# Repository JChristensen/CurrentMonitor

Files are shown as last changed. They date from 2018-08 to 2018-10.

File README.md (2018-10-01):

# Current Monitor
https://github.com/JChristensen/CurrentMonitor  
README file  
Jack Christensen  
Aug-2018

## License
  
Current Monitor by Jack Christensen is licensed under a [Creative Commons Attribution-ShareAlike 4.0 International License](http://creativecommons.org/licenses/by-sa/4.0/).

## Overview
The Current Monitor is an Arduino Uno-compatible board designed to function as a sensor node in an XBee network. While the board was primarily designed to interface to current transformers, it is also general enough to have wider applicability. Features include:
- ATmega328P microcontroller
- interface circuitry for two current transformers
- two analog pins (for current transformers) and four digital pins brought out to screw-type terminal blocks
- three on-board LEDs
- interface circuitry and 3.3V supply for the XBee module
- powered from most any 7-12VDC wall wart with a 2.5mm plug

[Hardware design](https://github.com/JChristensen/CurrentMonitor) and [an Arduino Current Transformer library](https://github.com/JChristensen/CurrentTransformer) are available on GitHub.  
PC boards can be ordered from [OSH Park](https://www.oshpark.com/shared_projects/QCjudQBh).  
A bill of materials is available at [Mouser Electronics](https://www.mouser.com/ProjectManager/ProjectDetail.aspx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) and also in the [GitHub repo](https://github.com/JChristensen/CurrentMonitor).  

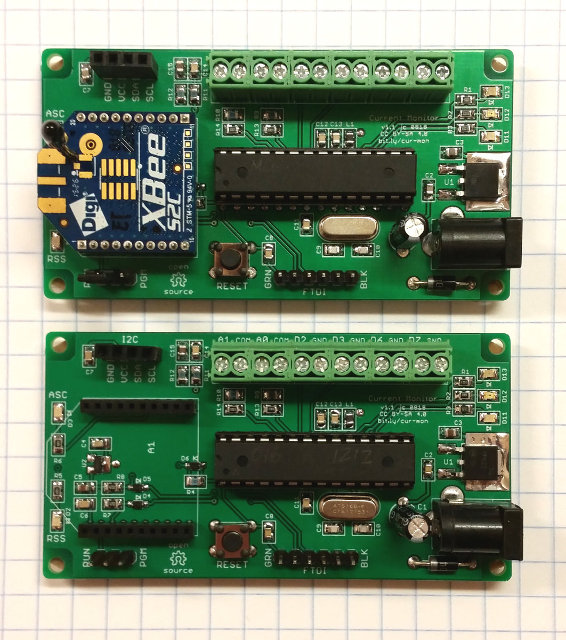
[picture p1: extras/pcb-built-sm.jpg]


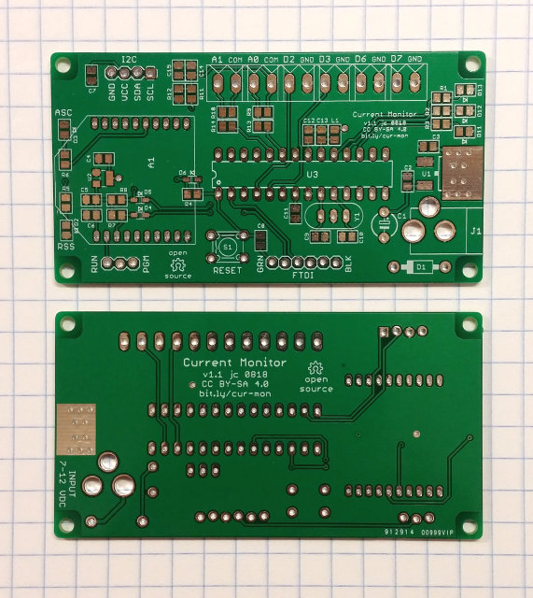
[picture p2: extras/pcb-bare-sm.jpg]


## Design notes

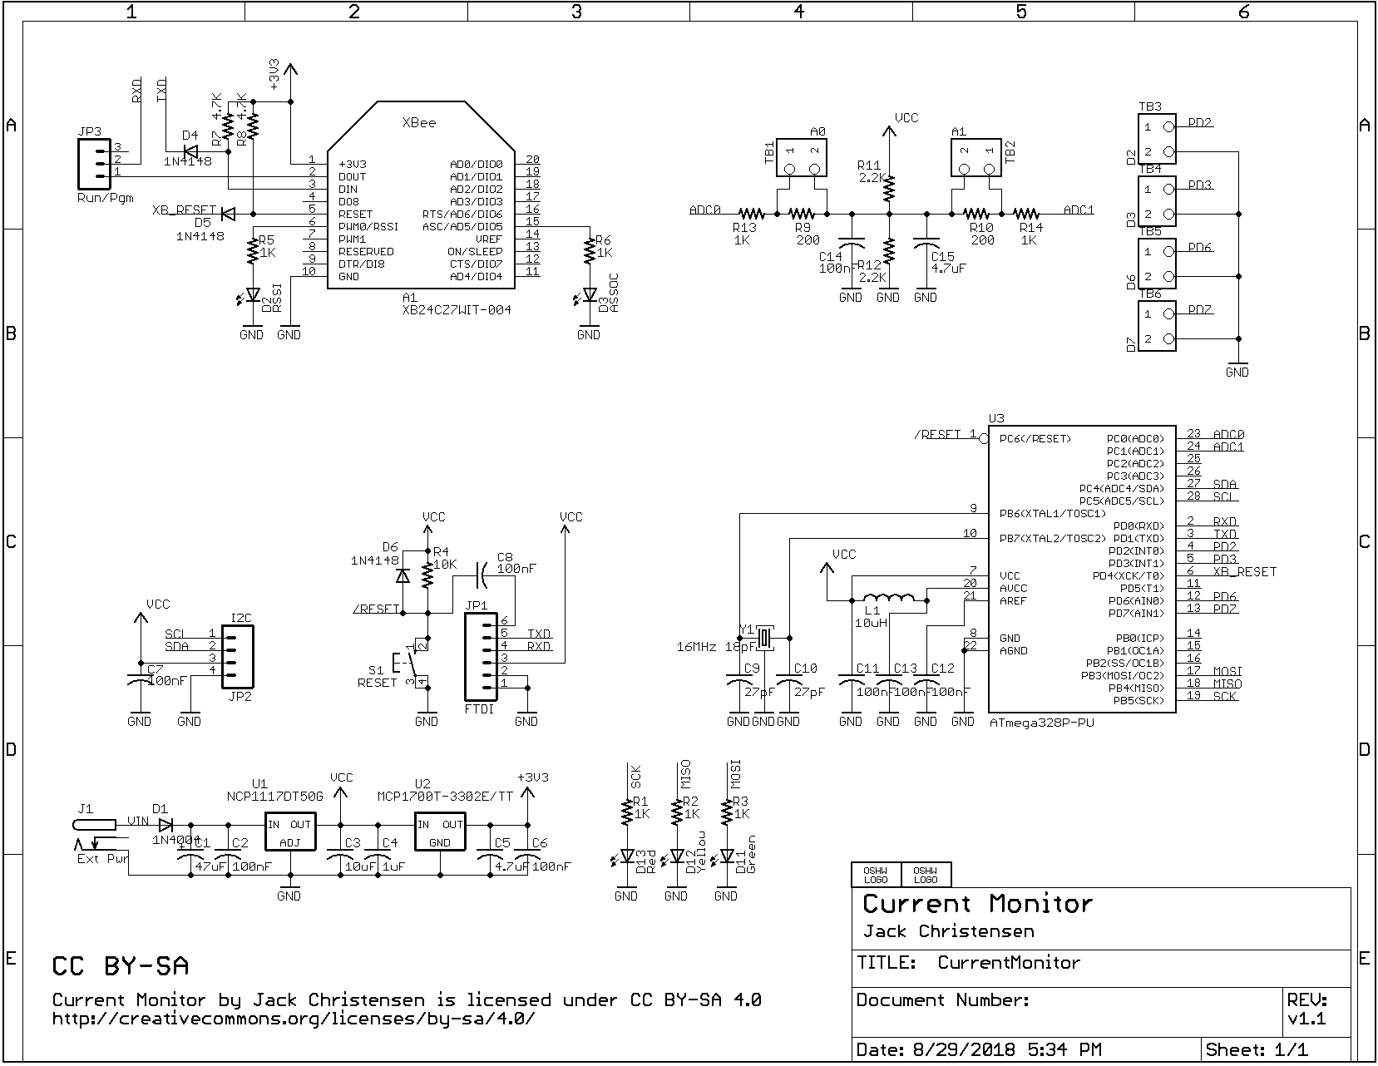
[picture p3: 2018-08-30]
schematic.png

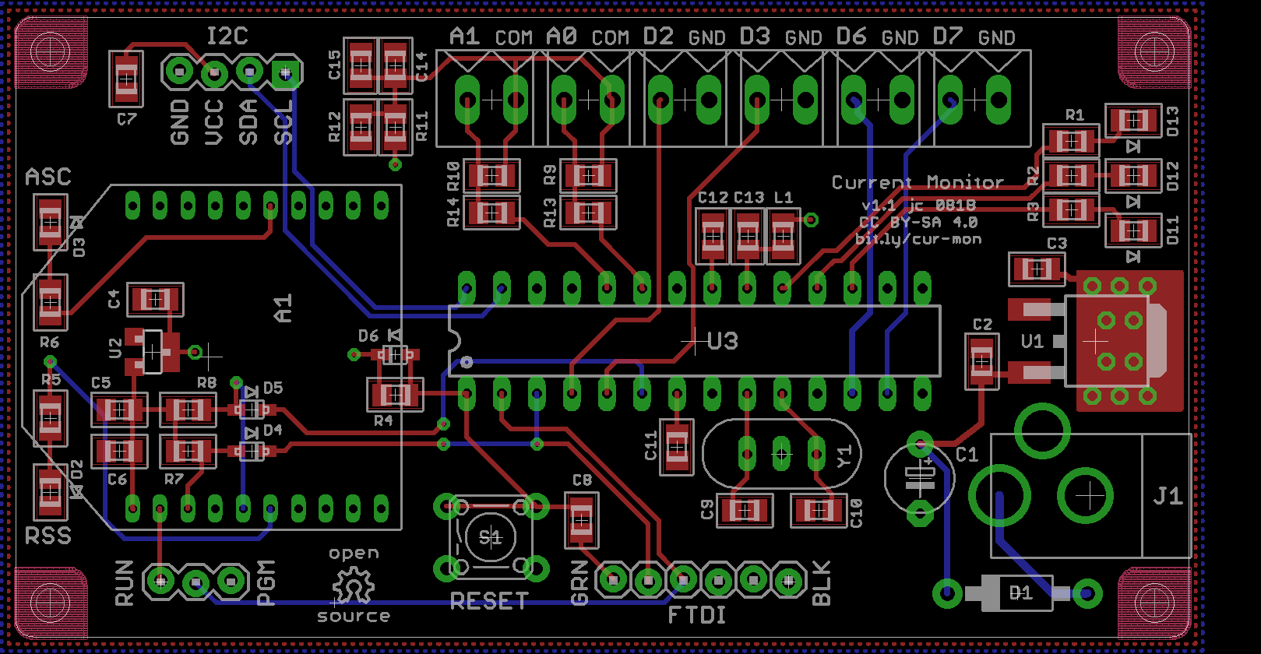
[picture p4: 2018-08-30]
board.png

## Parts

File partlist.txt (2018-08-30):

Partlist

Exported from CurrentMonitor.sch at 8/30/2018 4:15 PM

EAGLE Version 7.5.0 Copyright (c) 1988-2015 CadSoft

Assembly variant: 

Part     Value             Device             Package        Library  Sheet

A1       XB24CZ7WIT-004    ULINK_XBEEOVALPADS XBEE_OVAL_PADS _jc      1
C1       47uF              CPOL-USE5-5        E5-5           _jc      1
C2       100nF             C-USM0805          M0805          _jc      1
C3       10uF              C-USM0805          M0805          _jc      1
C4       1uF               C-USM0805          M0805          _jc      1
C5       4.7uF             C-USM0805          M0805          _jc      1
C6       100nF             C-USM0805          M0805          _jc      1
C7       100nF             C-USM0805          M0805          _jc      1
C8       100nF             C-USM0805          M0805          _jc      1
C9       27pF              C-USM0805          M0805          _jc      1
C10      27pF              C-USM0805          M0805          _jc      1
C11      100nF             C-USM0805          M0805          _jc      1
C12      100nF             C-USM0805          M0805          _jc      1
C13      100nF             C-USM0805          M0805          _jc      1
C14      100nF             C-USM0805          M0805          _jc      1
C15      4.7uF             C-USM0805          M0805          _jc      1
D1       1N4004            DIODE1N400X        1N400X         _jc      1
D2       RSSI              LEDD0805A          D0805A         _jc      1
D3       ASSOC             LEDD0805           D0805          _jc      1
D4       1N4148            DIODESOD-323F-A    SOD-323F-A     _jc      1
D5       1N4148            DIODESOD-323F-A    SOD-323F-A     _jc      1
D6       1N4148            DIODESOD-323F      SOD-323F       _jc      1
D11      Green             LEDD0805           D0805          _jc      1
D12      Yellow            LEDD0805           D0805          _jc      1
D13      Red               LEDD0805           D0805          _jc      1
J1       Ext Pwr           POWER-JACK         KLDX-0202      _jc      1
JP1      FTDI              M06LOCK            1X06_LOCK      SparkFun 1
JP2      I2C               M04LOCK            1X04_LOCK      SparkFun 1
JP3      Run/Pgm           M03LOCK            1X03_LOCK      SparkFun 1
L1       10uH              INDUCTORM0805      M0805          _jc      1
R1       1K                R-US_M0805         M0805          _jc      1
R2       1K                R-US_M0805         M0805          _jc      1
R3       1K                R-US_M0805         M0805          _jc      1
R4       10K               R-US_M0805         M0805          _jc      1
R5       1K                R-US_M0805         M0805          _jc      1
R6       1K                R-US_M0805         M0805          _jc      1
R7       4.7K              R-US_M0805         M0805          _jc      1
R8       4.7K              R-US_M0805         M0805          _jc      1
R9       200               R-US_M0805         M0805          _jc      1
R10      200               R-US_M0805         M0805          _jc      1
R11      2.2K              R-US_M0805         M0805          _jc      1
R12      2.2K              R-US_M0805         M0805          _jc      1
R13      1K                R-US_M0805         M0805          _jc      1
R14      1K                R-US_M0805         M0805          _jc      1
S1       RESET             10-XXOCT           B3F-10XXOCT    _jc      1
TB1      A0                OST-TB-23.5MM      OST-TB-2-3.5MM _jc      1
TB2      A1                OST-TB-23.5MM      OST-TB-2-3.5MM _jc      1
TB3      D2                OST-TB-23.5MM      OST-TB-2-3.5MM _jc      1
TB4      D3                OST-TB-23.5MM      OST-TB-2-3.5MM _jc      1
TB5      D6                OST-TB-23.5MM      OST-TB-2-3.5MM _jc      1
TB6      D7                OST-TB-23.5MM      OST-TB-2-3.5MM _jc      1
U1       NCP1117DT50G      LD117ADT50TR       DPACK          v-reg    1
U2       MCP1700T-3302E/TT MCP1700SOT23-W     SOT23-W        _jc      1
U3       ATmega328P-PU     AVR-MEGA8-PPTH     DIL28-3        SparkFun 1
Y1       16MHz 18pF        RESONATOR          RESONATOR      _jc      1

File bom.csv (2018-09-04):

Current Monitor
Bill of materials
https://www.mouser.com/ProjectManager/ProjectDetail.aspx?AccessID=cceb9dd570
Part No. | Order Qty. | Mouser # | Mfr. # | Manufacturer | Description
A1 | 2 | 855-M22-7131042 | M22-7131042 | Harwin | Headers & Wire Housings 10 PIN SIL VERTICAL GOLD+TIN SOCKET
A1 | 1 | 888-XB24CZ7WIT-004 | XB24CZ7WIT-004 | Digi International | Zigbee Modules (802.15.4) XBee ZB S2C TH Wire Antenna
C1 | 1 | 667-ECA-1CM470B | ECA-1CM470B | Panasonic | Aluminum Electrolytic Capacitors - Radial Leaded Al Lytic Cap 85C Radial M Series
C2, C6, C7, C8, C11-14 | 8 | 581-08053C104K | 08053C104KAT2A | AVX | Multilayer Ceramic Capacitors MLCC - SMD/SMT 25V .1uF X7R 0805 10%
C3 | 1 | 963-LMK212BJ106KG-T | LMK212BJ106KG-T | Taiyo Yuden | Multilayer Ceramic Capacitors MLCC - SMD/SMT 10uF 10V X5R +/-10% 0805 Gen Purp
C4 | 1 | 81-GRM21BR61C105KA1K | GRM21BR61C105KA01K | Murata | Multilayer Ceramic Capacitors MLCC - SMD/SMT 1uf 16V X5R +/-10% 0805
C5, C15 | 2 | 963-LMK212B7475KG-T | LMK212B7475KG-T | Taiyo Yuden | Multilayer Ceramic Capacitors MLCC - SMD/SMT 4.7uF 10V X7R +/-10% 0805 Gen Purp
C9, C10 | 2 | 603-CC805JRNPO9BN270 | CC0805JRNPO9BN270 | Yageo | Multilayer Ceramic Capacitors MLCC - SMD/SMT 27pF 50V NPO 5%
D1 | 1 | 863-1N4004G | 1N4004G | ON Semiconductor | Rectifiers 400V 1A Standard
D12 | 1 | 859-LTST-C171KSKT | LTST-C171KSKT | Lite-On | Standard LEDs - SMD Yellow Clear 587nm
D2, D13 | 2 | 859-LTST-C171KRKT | LTST-C171KRKT | Lite-On | Standard LEDs - SMD Red Clear 55MCD
D3, D11 | 2 | 859-LTST-C171KGKT | LTST-C171KGKT | Lite-On | Standard LEDs - SMD Green Clear 571nm
D4, D5, D6 | 3 | 512-1N4148WS | 1N4148WS | ON Semiconductor | Diodes - General Purpose, Power, Switching Small Signal Diode
J1 | 1 | 806-KLDX-0202-B | KLDX-0202-B | Kycon | DC Power Connectors 2.5mm PCB JACK POWER JACK
JP1 | 1 |  |  |  | 0.1” Header, male, 6-position
JP2 | 1 |  |  |  | 0.1” Header, female, 4-position
JP3 | 1 |  |  |  | 0.1” Header, male, 3-position
JP3 | 1 |  |  |  | Shorting block for 0.1” header
L1 | 1 | 963-LBR2012T100K | LBR2012T100K | Taiyo Yuden | Fixed Inductors 0805 10uH 468mOhms +/-10%Tol 150mA
R1-3, R5-6, R13-14 | 7 | 603-RC0805FR-071KL | RC0805FR-071KL | Yageo | Thick Film Resistors - SMD 1K OHM 1%
R11, R12 | 2 | 603-RC0805FR-072K2L | RC0805FR-072K2L | Yageo | Thick Film Resistors - SMD 2.2K OHM 1%
R4 | 1 | 603-RC0805FR-1310KL | RC0805FR-1310KL | Yageo | Thick Film Resistors - SMD 10K OHM 1%
R7, R8 | 2 | 603-RC0805FR-074K7L | RC0805FR-074K7L | Yageo | Thick Film Resistors - SMD 4.7K OHM 1%
R9, R10 | 2 | 603-RC0805FR-07200RL | RC0805FR-07200RL | Yageo | Thick Film Resistors - SMD 200 OHM 1%
S1 | 1 | 653-B3F-1020 | B3F-1020 | Omron | Tactile Switches 6X6 Flat 5mm Btn Force 100g w/o Grd
TB1/2, TB3/4, TB5/6 | 3 | 651-1984633 | 1984633 | Phoenix Contact | Fixed Terminal Blocks PT 1.5/4-3.5H 4POS HRZ 3.5mm SCREW
U1 | 1 | 863-NCP1117DT50G | NCP1117DT50G | ON Semiconductor | LDO Voltage Regulators 5.0V 1A Positive
U2 | 1 | 579-MCP1700T3302E/TT | MCP1700T-3302E/TT | Microchip | LDO Voltage Regulators 250mA Adj LDO 2%
U3 | 1 | 556-ATMEGA328P-PU | ATMEGA328P-PU | Microchip | 8-bit Microcontrollers - MCU 32KB In-system Flash 20MHz 1.8V-5.5V
Y1 | 1 | 815-ABL-16-B4Y | ABL-16.000MHz-B4Y | ABRACON | Crystals 16.000MHZ, 18pF 30ppm -20C +70C

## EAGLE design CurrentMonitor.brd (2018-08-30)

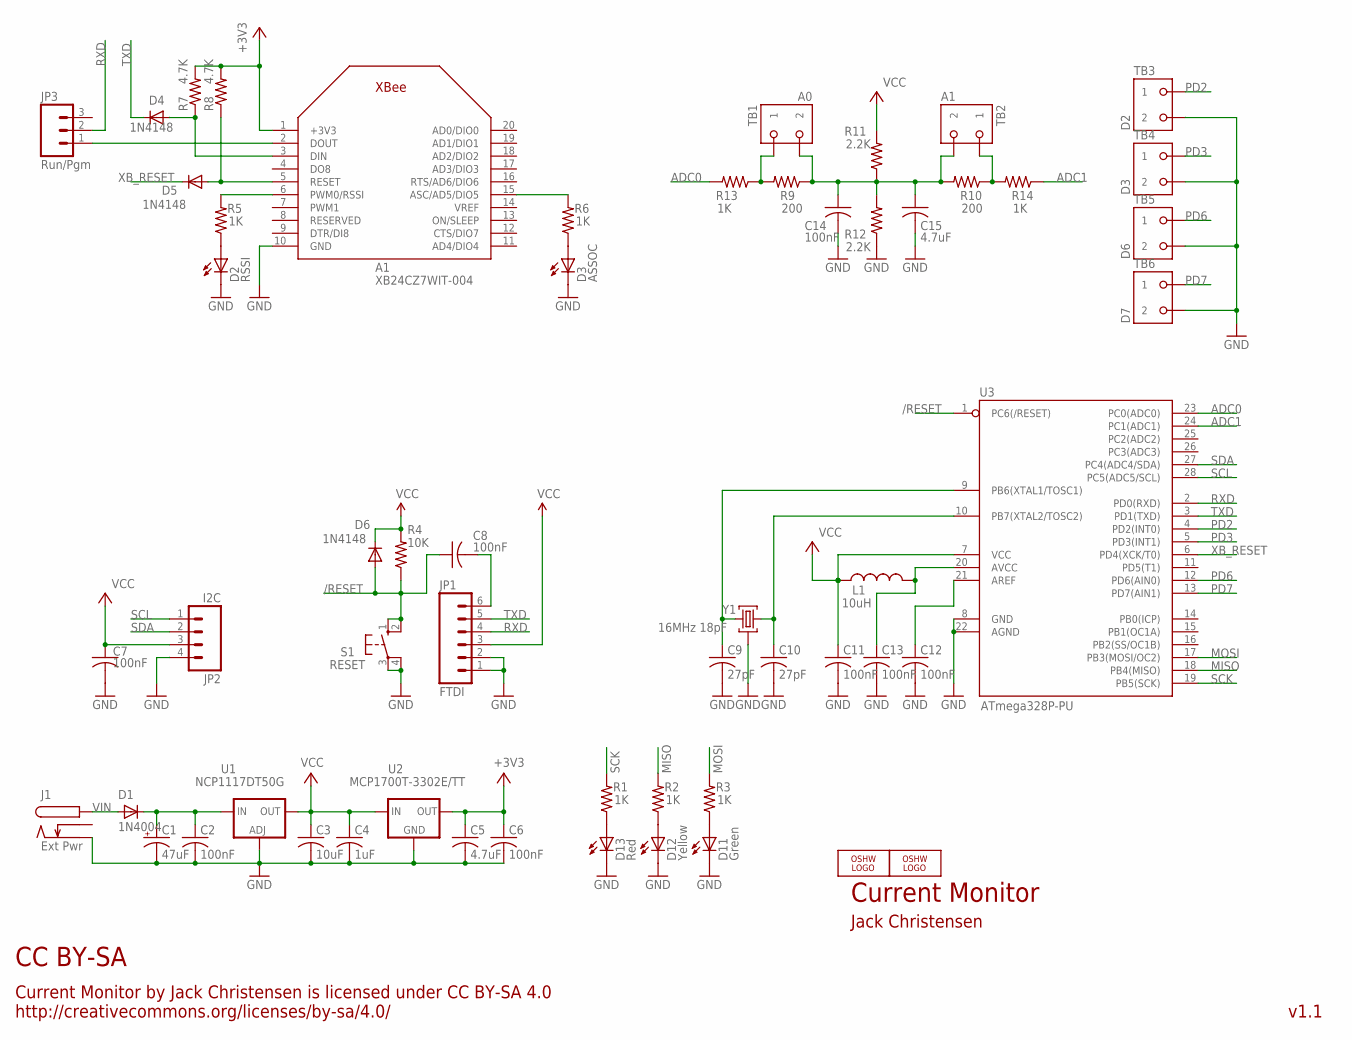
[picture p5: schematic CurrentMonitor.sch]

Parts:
A1: XB24CZ7WIT-004; XBEE_OVAL_PADS
C1: 47uF; E5-5
C2, C6, C7, C8, C11, C12, C13, C14: 100nF; M0805
C3: 10uF; M0805
C4: 1uF; M0805
C5, C15: 4.7uF; M0805
C9, C10: 27pF; M0805
D1: 1N4004; 1N400X
D2: RSSI; D0805A
D3: ASSOC; D0805
D4, D5: 1N4148; SOD-323F-A
D6: 1N4148; SOD-323F
D11: Green; D0805
D12: Yellow; D0805
D13: Red; D0805
J1: Ext Pwr; KLDX-0202
JP1: FTDI; 1X06_LOCK
JP2: I2C; 1X04_LOCK
JP3: Run/Pgm; 1X03_LOCK
L1: 10uH; M0805
LOGO1, LOGO2: OSHW_LOGO_8MILX0100-NT; OSHW_8X100_NOTEXT
R1, R2, R3, R5, R6, R13, R14: 1K; M0805
R4: 10K; M0805
R7, R8: 4.7K; M0805
R9, R10: 200; M0805
R11, R12: 2.2K; M0805
S1: RESET; B3F-10XXOCT
TB1: A0; OST-TB-2-3.5MM
TB2: A1; OST-TB-2-3.5MM
TB3: D2; OST-TB-2-3.5MM
TB4: D3; OST-TB-2-3.5MM
TB5: D6; OST-TB-2-3.5MM
TB6: D7; OST-TB-2-3.5MM
U1: NCP1117DT50G; DPACK
U2: MCP1700T-3302E/TT; SOT23-W
U3: ATmega328P-PU; DIL28-3
Y1: 16MHz 18pF; RESONATOR

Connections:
+3V3: A1.1 (+3V3), C5.1, C6.1, R7.2, R8.2, U2.2 (OUT)
/RESET: C8.1, D6.A, R4.1, S1.1 (S), S1.2 (S1), U3.1 (PC6(/RESET))
ADC0: R13.2, U3.23 (PC0(ADC0))
ADC1: R14.1, U3.24 (PC1(ADC1))
GND: A1.10 (GND), C1.-, C2.2, C3.2, C4.2, C5.2, C6.2, C7.2, C9.2, C10.2, C11.2, C12.2, C13.2, C14.2, C15.2, D2.K (C), D3.K (C), D11.K (C), D12.K (C), D13.K (C), J1.P$2, JP1.1, JP1.2, JP2.4, R12.1, S1.3, S1.4 (P1), TB3.P$2 (2), TB4.P$2 (2), TB5.P$2 (2), TB6.P$2 (2), U1.1 (ADJ), U2.1 (GND), U3.8 (GND), U3.22 (AGND), Y1.2
MISO: R2.2, U3.18 (PB4(MISO))
MOSI: R3.2, U3.17 (PB3(MOSI/OC2))
unnamed: D13.A, R1.1
unnamed: D1.A, J1.P$1
unnamed: C14.1, C15.1, R9.1, R10.2, R11.1, R12.2, TB1.P$2 (2), TB2.P$2 (2)
unnamed: C10.1, U3.10 (PB7(XTAL2/TOSC2)), Y1.3
unnamed: C13.1, L1.2, U3.20 (AVCC)
unnamed: C9.1, U3.9 (PB6(XTAL1/TOSC1)), Y1.1
unnamed: C12.1, U3.21 (AREF)
unnamed: A1.3 (DIN), D4.A, R7.1
unnamed: D12.A, R2.1
unnamed: A1.2 (DOUT), JP3.1
unnamed: D2.A, R5.1
unnamed: D3.A, R6.1
unnamed: A1.6 (PWM0/RSSI), R5.2
unnamed: A1.15 (ASC/AD5/DIO5), R6.2
unnamed: R9.2, R13.1, TB1.P$1 (1)
unnamed: R10.1, R14.2, TB2.P$1 (1)
unnamed: A1.5 (RESET), D5.A, R8.1
unnamed: D11.A, R3.1
PD2: TB3.P$1 (1), U3.4 (PD2(INT0))
PD3: TB4.P$1 (1), U3.5 (PD3(INT1))
PD6: TB5.P$1 (1), U3.12 (PD6(AIN0))
PD7: TB6.P$1 (1), U3.13 (PD7(AIN1))
RST: C8.2, JP1.6
RXD: JP1.4, JP3.2, U3.2 (PD0(RXD))
SCK: R1.2, U3.19 (PB5(SCK))
SCL: JP2.1, U3.28 (PC5(ADC5/SCL))
SDA: JP2.2, U3.27 (PC4(ADC4/SDA))
TXD: D4.K, JP1.5, U3.3 (PD1(TXD))
VCC: C3.1, C4.1, C7.1, C11.1, D6.K, JP1.3, JP2.3, L1.1, R4.2, R11.2, U1.4 (OUT), U2.3 (IN), U3.7 (VCC)
VIN: C1.+, C2.1, D1.K, U1.3 (IN)
XB_RESET: D5.K, U3.6 (PD4(XCK/T0))

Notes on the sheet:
Current Monitor
Jack Christensen
Current Monitor by Jack Christensen is licensed under CC BY-SA 4.0 http://creativecommons.org/licenses/by-sa/4.0/
CC BY-SA
v1.1

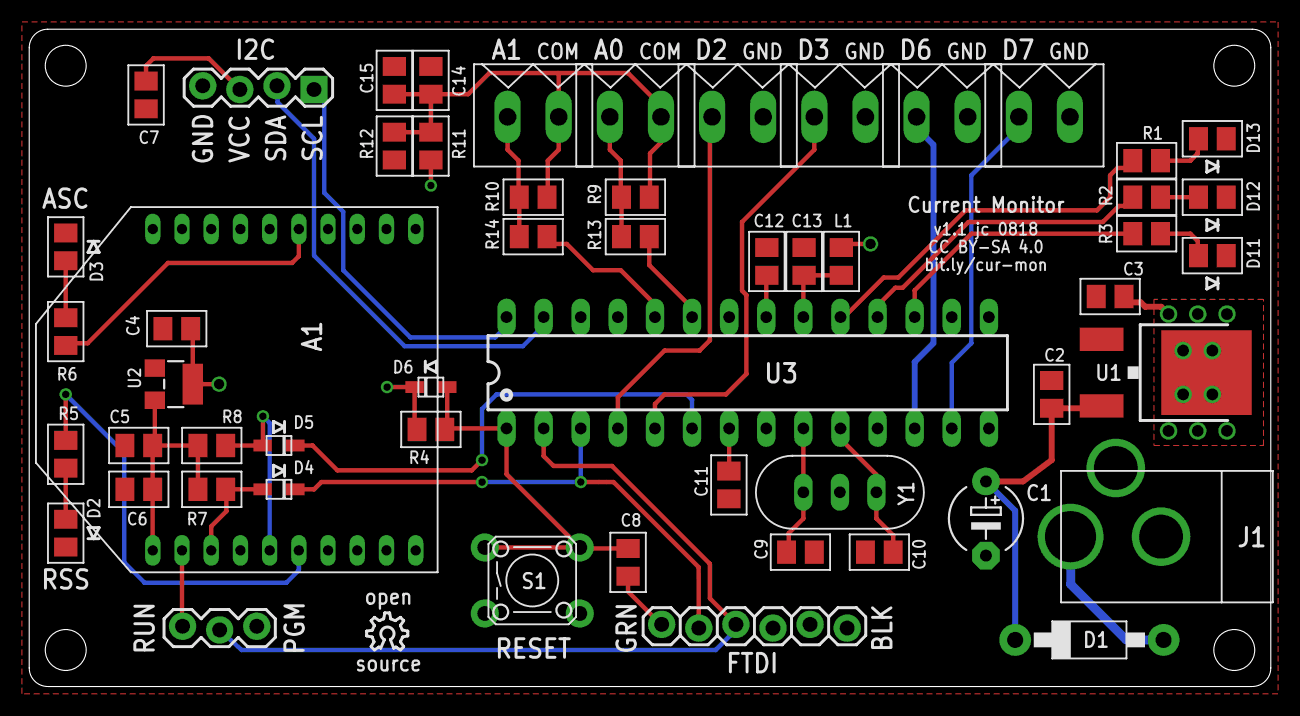
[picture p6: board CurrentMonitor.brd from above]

Board: 2 copper layers, 85.0 x 45.0 mm, 57 parts (1 on the bottom side), 38 nets.

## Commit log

2018-08-29 Initial commit.
    [CurrentMonitor.brd, CurrentMonitor.sch]
2018-08-29 Add terminal blocks for additional GPIO and LEDs.
    [CurrentMonitor.brd, CurrentMonitor.sch]
2018-08-29 Layout tweaks.
    [CurrentMonitor.brd, CurrentMonitor.sch]
2018-08-29 Enlarge via for Vcc.
    [CurrentMonitor.brd]
2018-08-29 Change Run/Pgm header to "lock" package.
    [CurrentMonitor.brd, CurrentMonitor.sch]
2018-08-30 Minor board layout tweaks.
    [CurrentMonitor.brd]
2018-09-04 Add bill of materials.
    [bom.csv, bom.ods]

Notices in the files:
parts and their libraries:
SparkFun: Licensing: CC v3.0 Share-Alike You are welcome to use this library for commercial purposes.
